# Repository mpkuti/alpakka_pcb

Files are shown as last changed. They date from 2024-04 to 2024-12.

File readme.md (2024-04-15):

# Alpakka PCB

*Alpakka controller Printed Circuit Board reference design*

## Project links
- [Alpakka Manual](https://inputlabs.io/devices/alpakka/manual).
- [Alpakka Firmware](https://github.com/inputlabs/alpakka_firmware).
- [Alpakka PCB](https://github.com/inputlabs/alpakka_pcb). _(you are here)_
- [Alpakka 3D-print](https://github.com/inputlabs/alpakka_case).
- [Input Labs Roadmap](https://github.com/orgs/inputlabs/projects/2/views/2).

## Previews



## Order a PCB from the reference design
For ordering a reference design PCB (with no modifications) is possible to use the pre-built [order files](https://github.com/inputlabs/alpakka_pcb/releases). Check the [manual](https://inputlabs.io/devices/alpakka/manual/diy_pcb) for step-by-step instructions.

## Modify the schematics and PCB

### Dependencies
- [KiCad 8](https://www.kicad.org)

### Change components for SMT pick & place

- Open `.kicad_sch` file in Schematics editor.
- Go to menu `Tools` → `Edit symbol fields`
- Group by field `Group`
- Change id references (`LCSC id` for [JLCPCB](https://jlcpcb.com)).

### Generate order files from sources
- Copy `plugins/kicad_ilo_export.py` into KiCad plugins folder (PCB editor → menu `Tools` → `External plugins` → `Reveal plugins folder`).
- Open `.kicad_pcb` file in PCB editor.
- Use menu `Edit` → `Fill all zones`
- Go to menu `Tools` → `External plugins` → `Refresh plugins`
- Go to menu `Tools` → `External plugins` → `Input Labs: export`
- Files are generated into `order/`

### If the plugin does not load correctly
- Open `Preferences` → `Action plugins`
- Check that the plugin is installed correctly / check errors.

### Procedural zones
Consolidated zones increase `.kicad_pcb` file size significantly, so instead is recommended to load and save the project without consolidation:

- After loading the PCB project: `Edit` → `Fill all zones`.
- Before saving the PCB project: `Edit` → `Unfill all zones`.

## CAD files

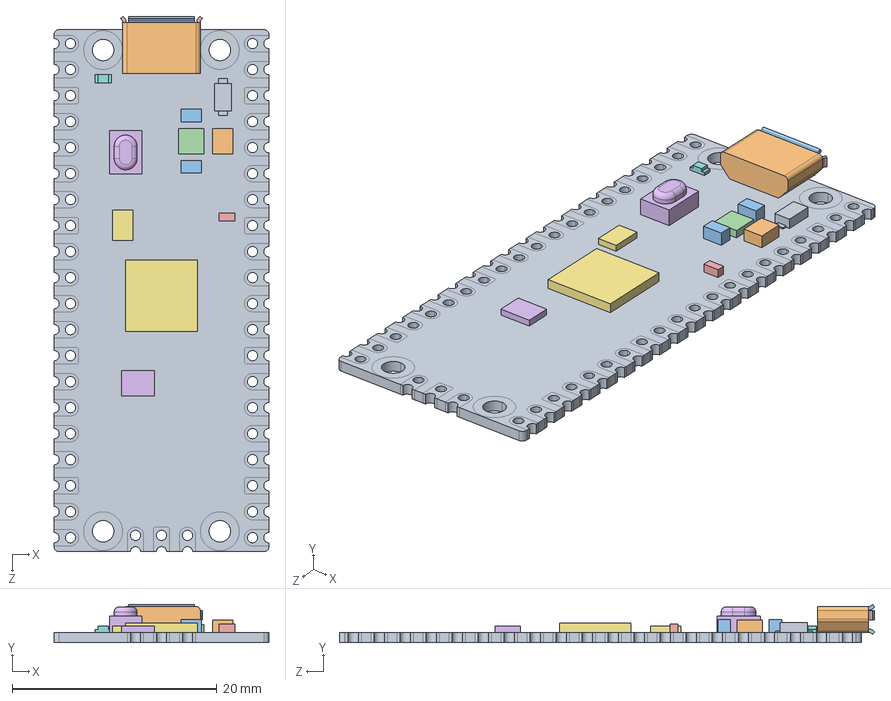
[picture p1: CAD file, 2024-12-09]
symbols/step/Pico-R3.step
21.0 x 3.73 x 52.3 mm
PICO_REF_BOARD.STEP
PICO_REF_USB.STEP
PICO_REF_SWITCH.STEP
PICO_REF_MICROCONTROLLER.STEP
PICO_REF_LED.STEP
PICO_REF_ONSEMI.STEP
PICO_BOURNS.STEP
PICO_MURATA.STEP x 2
PICO_RICHTEK.STEP
PICO_DIODES.STEP
PICO_AEL.STEP
PICO_WINBOND.STEP

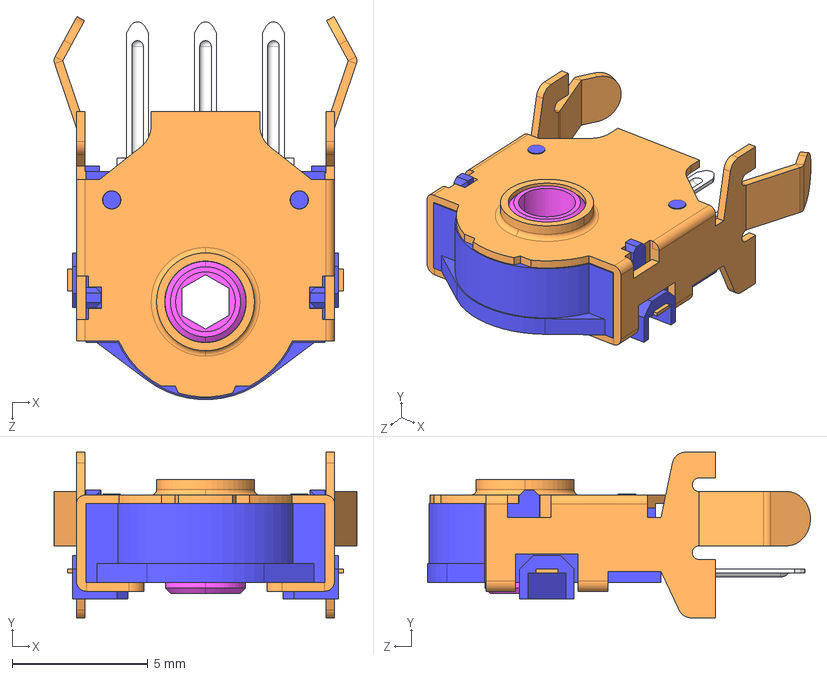
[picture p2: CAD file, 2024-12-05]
symbols/step/EC10E12_H07.STEP
11.1 x 6.10 x 14.1 mm

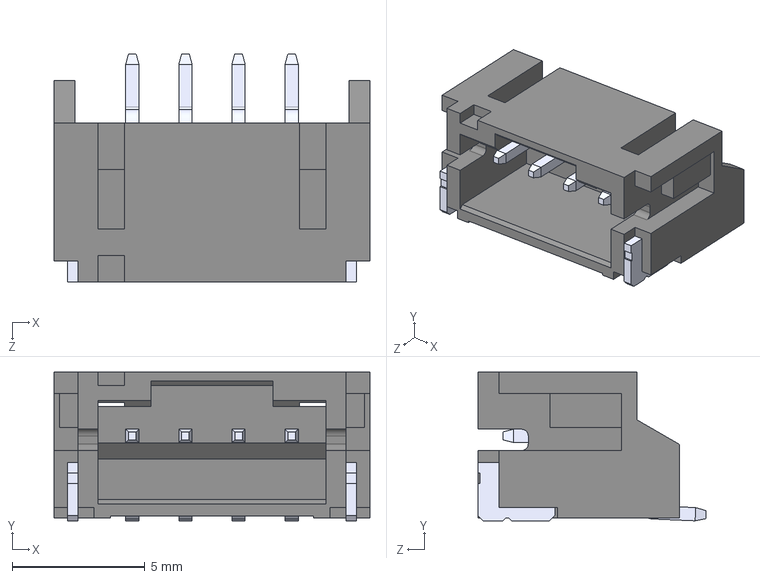
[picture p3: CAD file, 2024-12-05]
symbols/step/S4B-PH-SM4-K-TB (LF)(SN)--3DModel-STEP-56544.STEP
11.9 x 5.60 x 8.60 mm

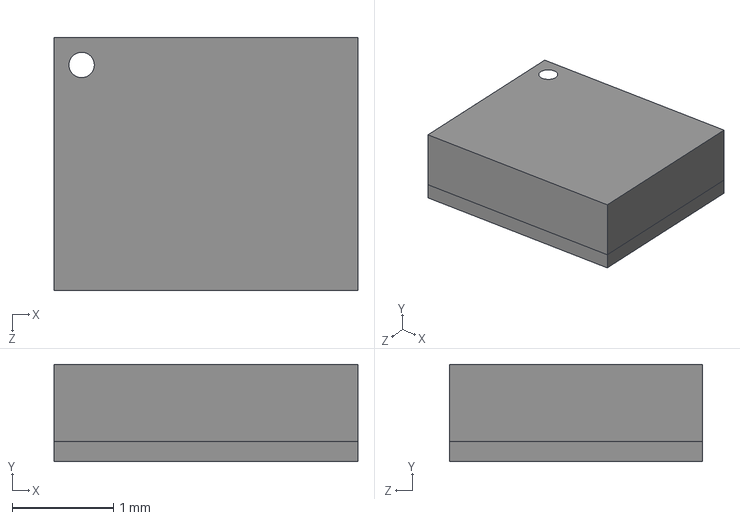
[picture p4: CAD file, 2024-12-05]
symbols/step/LSM6DSRTR.STEP
3.00 x 0.96 x 2.50 mm

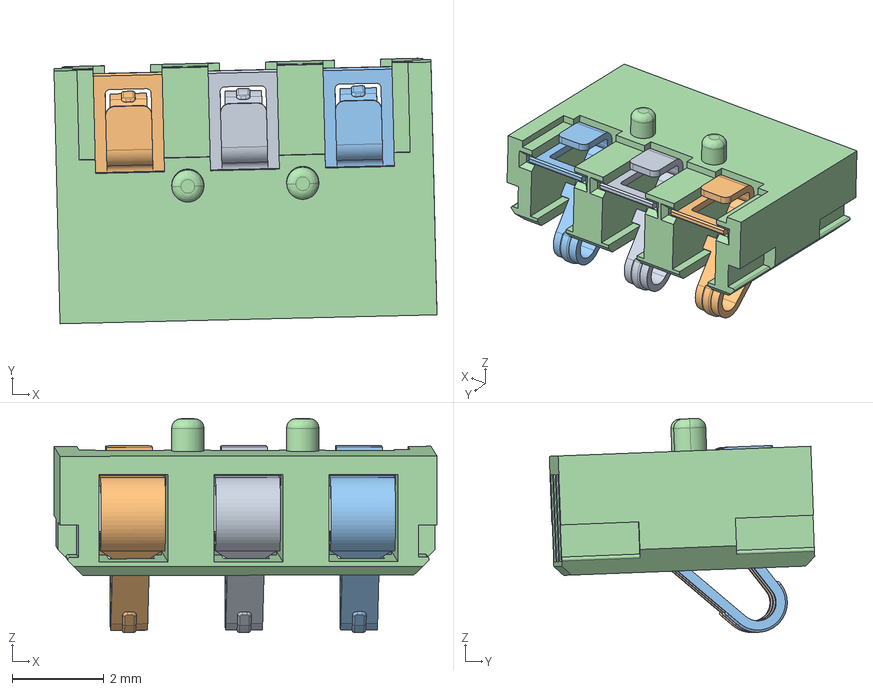
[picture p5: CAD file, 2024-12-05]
symbols/step/304D-262503.stp
8.33 x 5.77 x 4.66 mm
MSBR-4_1
MSBR-3_1
MSBR-2_1
MSBR-1_1

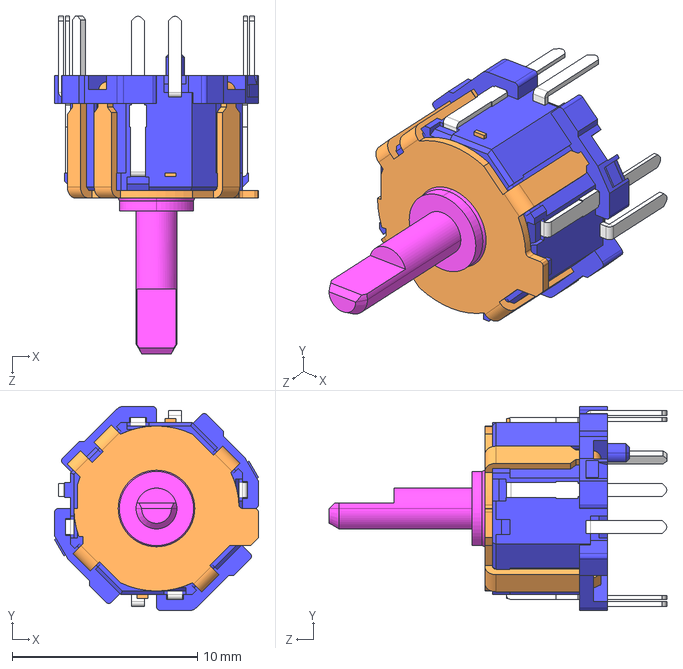
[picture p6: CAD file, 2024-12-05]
symbols/step/RKJXM1015004.STEP
11.0 x 11.0 x 18.2 mm

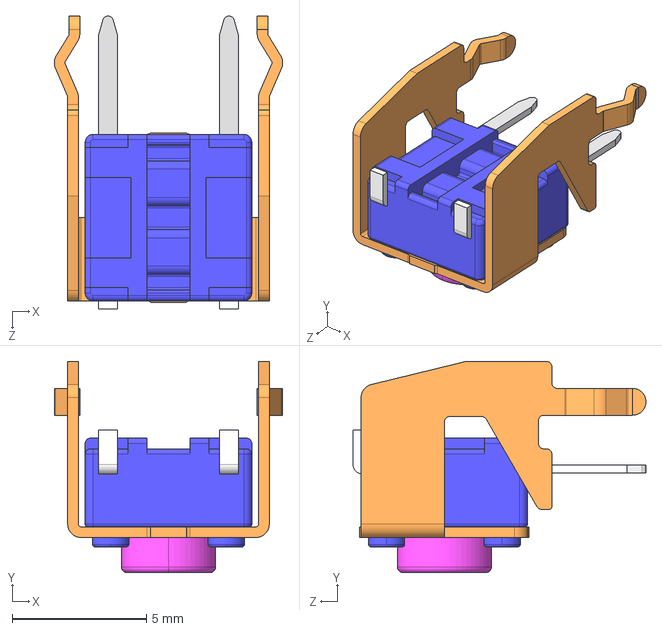
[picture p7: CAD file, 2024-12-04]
symbols/step/SKHHLN.STEP
8.50 x 7.85 x 10.9 mm

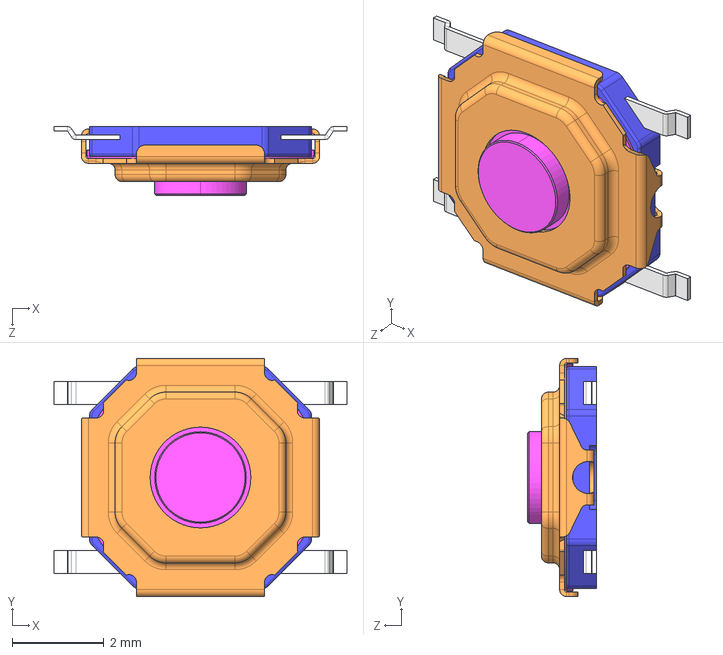
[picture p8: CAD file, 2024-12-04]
symbols/step/SKQGAF.STEP
6.40 x 5.20 x 1.50 mm

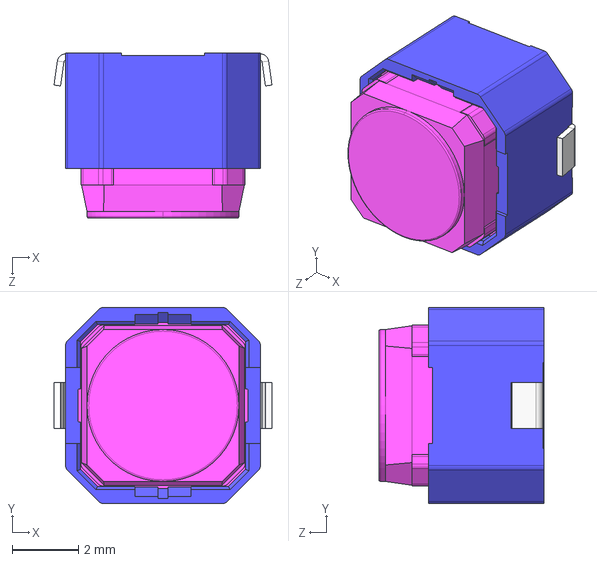
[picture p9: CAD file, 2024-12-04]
symbols/step/SKPMAM.STEP
6.60 x 5.94 x 5.00 mm

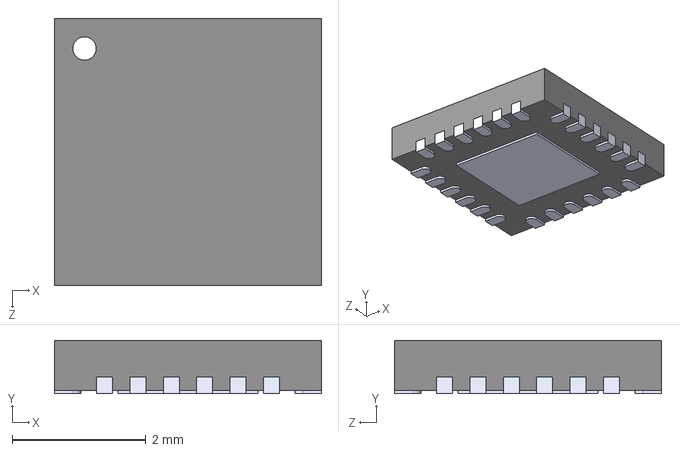
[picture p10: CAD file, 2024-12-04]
symbols/step/PCAL6416AHF,128.STEP
4.00 x 0.8 x 4.00 mm

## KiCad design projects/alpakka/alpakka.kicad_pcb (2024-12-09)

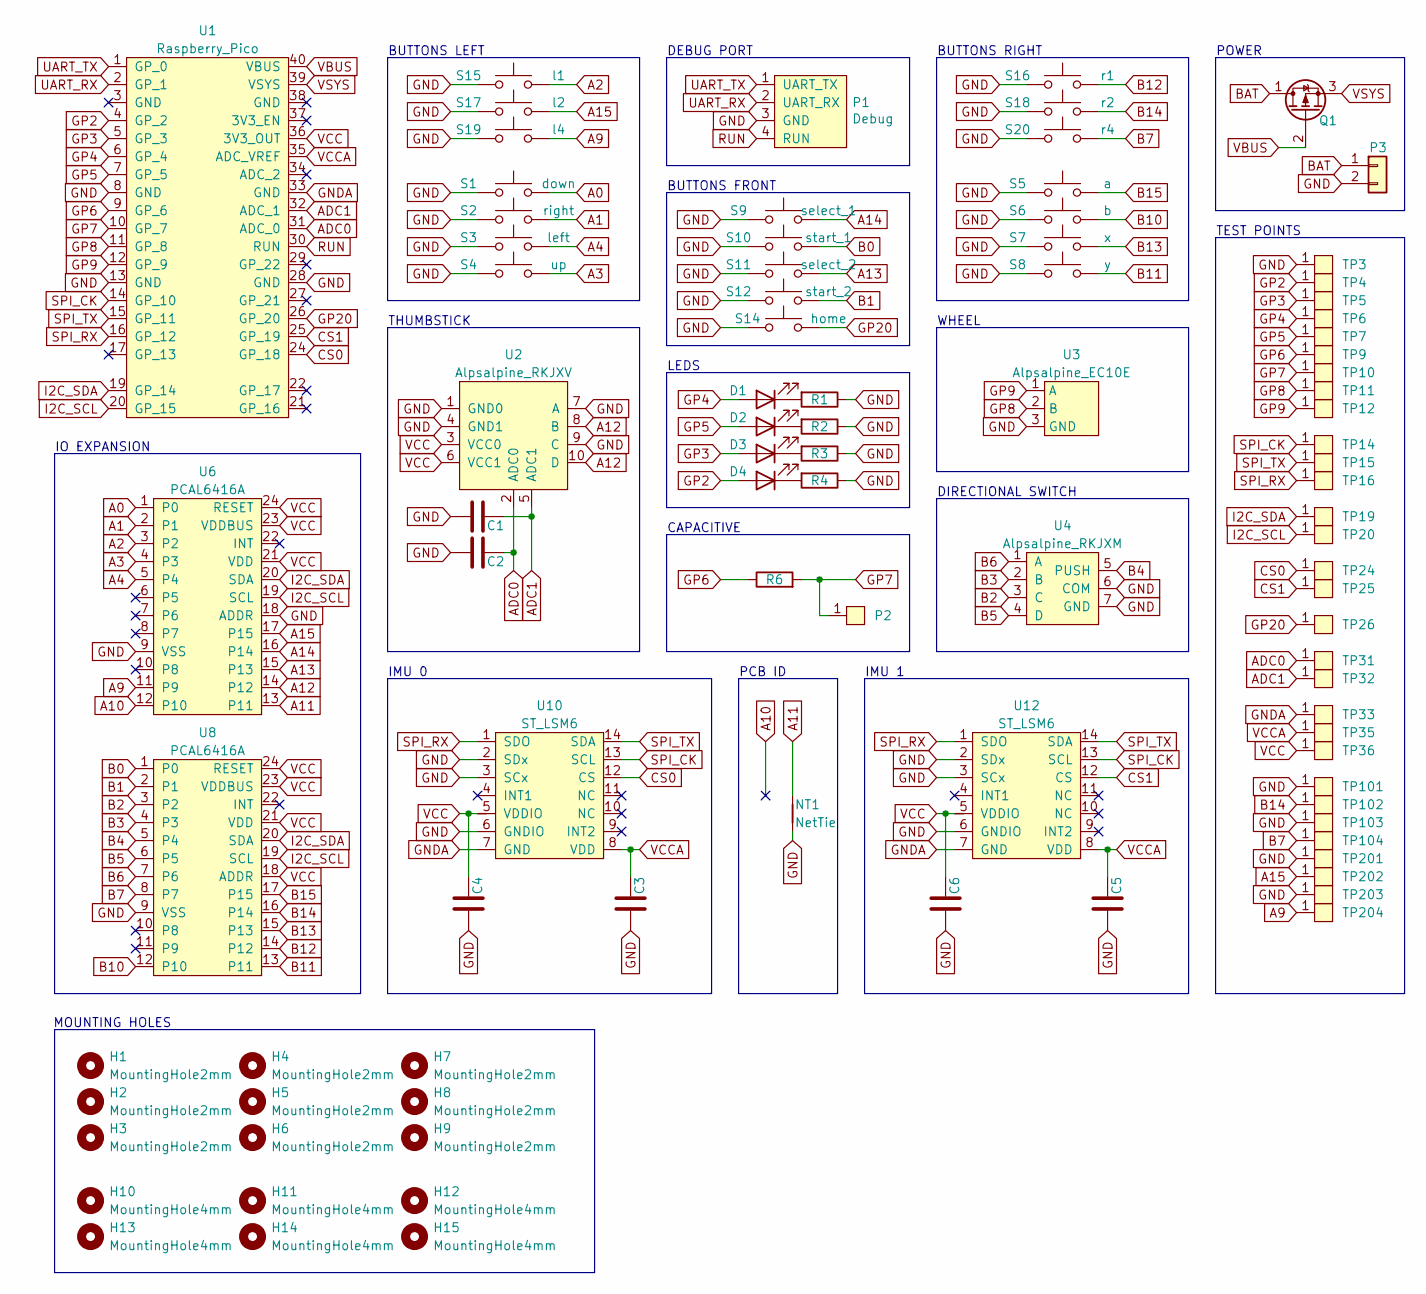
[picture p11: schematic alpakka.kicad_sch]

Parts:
C1, C2, C3, C4, C5, C6: 0.1µF; C_0402_1005Metric_Pad0.74x0.62mm_HandSolder; LCSC C1525
D1, D2, D3, D4: Diode; D_0603_1608Metric_Pad1.05x0.95mm_HandSolder; LCSC C2290
H1, H2, H3, H4, H5, H6, H7, H8, H9: MountingHole2mm; NPTH_2mm
H10, H11, H12, H13, H14, H15: MountingHole4mm; NPTH_4mm
NT1: NetTie; NetTie-2_SMD_Pad0.5mm
P1: Debug; JST_S4B-PH-SM4-K-TB; mouser# 306-S4BPHSM4KTBLFSN; LCSC C265332
P2: Endpoint; 304D-262503; LCSC C707322
P3: Conn_01x02; JST_PH_2_TH
Q1: Q_PMOS_DGS; SOT-23-DGS; digikey# DMG2305UX-7DICT-ND
R1, R2, R3, R4: 20Ω; R_0603_1608Metric_Pad0.98x0.95mm_HandSolder; LCSC C22950
R6: 510kΩ; R_0402_1005Metric_Pad0.72x0.64mm_HandSolder; LCSC C11616
S1: down; Alpsalpine_SKPM; LCSC C115348
S2: right; Alpsalpine_SKPM; LCSC C115348
S3: left; Alpsalpine_SKPM; LCSC C115348
S4: up; Alpsalpine_SKPM; LCSC C115348
S5: a; Alpsalpine_SKPM; LCSC C115348
S6: b; Alpsalpine_SKPM; LCSC C115348
S7: x; Alpsalpine_SKPM; LCSC C115348
S8: y; Alpsalpine_SKPM; LCSC C115348
S9: select_1; Alpsalpine_SKPM; LCSC C115348
S10: start_1; Alpsalpine_SKPM; LCSC C115348
S11: select_2; Alpsalpine_SKPM; LCSC C115348
S12: start_2; Alpsalpine_SKPM; LCSC C115348
S14: home; Alpsalpine_SKPM; LCSC C115348
S15: l1; Alpsalpine_SKHHL; LCSC C125031
S16: r1; Alpsalpine_SKHHL; LCSC C125031
S17: l2; Alpsalpine_SKQG; LCSC C202424
S18: r2; Alpsalpine_SKQG; LCSC C202424
S19: l4; Alpsalpine_SKQG; LCSC C202424
S20: r4; Alpsalpine_SKQG; LCSC C202424
TP3, TP4, TP5, TP6, TP7, TP9, TP10, TP11, TP12, TP14, TP15, TP16, TP19, TP20, TP24, TP25, TP26, TP31, TP32, TP33, TP35, TP36, TP101, TP102, TP103, TP104, TP201, TP202, TP203, TP204: Endpoint; Pad_1mm
U1: Raspberry_Pico; LCSC C7203002
U2: Alpsalpine_RKJXV; Alpsalpine_RKJXV122400R; mouser# 688-RKJXV122400R; LCSC C918854
U3: Alpsalpine_EC10E; LCSC C110291
U4: Alpsalpine_RKJXM; Alpsalpine_RKJXM1015004; LCSC C97432
U6, U8: PCAL6416A; QFN24; LCSC C2652287
U10, U12: ST_LSM6; LGA14; LCSC C784817

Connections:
A0: S1.2, U6.1 (P0)
A1: S2.2, U6.2 (P1)
A2: S15.2, U6.3 (P2)
A3: S4.2, U6.4 (P3)
A4: S3.2, U6.5 (P4)
A9: S19.2, TP204.1, U6.11 (P9)
A10: U6.12 (P10)
A11: NT1.2, U6.13 (P11)
A12: U2.8 (B), U2.10 (D), U6.14 (P12)
A13: S11.2, U6.15 (P13)
A14: S9.2, U6.16 (P14)
A15: S17.2, TP202.1, U6.17 (P15)
ADC0: C2.2, TP31.1, U1.31 (ADC_0), U2.2 (ADC0)
ADC1: C1.2, TP32.1, U1.32 (ADC_1), U2.5 (ADC1)
B0: S10.2, U8.1 (P0)
B1: S12.2, U8.2 (P1)
B2: U4.3 (C), U8.3 (P2)
B3: U4.2 (B), U8.4 (P3)
B4: U4.5 (PUSH), U8.5 (P4)
B5: U4.4 (D), U8.6 (P5)
B6: U4.1 (A), U8.7 (P6)
B7: S20.2, TP104.1, U8.8 (P7)
B10: S6.2, U8.12 (P10)
B11: S8.2, U8.13 (P11)
B12: S16.2, U8.14 (P12)
B13: S7.2, U8.15 (P13)
B14: S18.2, TP102.1, U8.16 (P14)
B15: S5.2, U8.17 (P15)
BAT: P3.1, Q1.1 (D)
CS0: TP24.1, U1.24 (GP_18), U10.12 (CS)
CS1: TP25.1, U1.25 (GP_19), U12.12 (CS)
GND: C1.1, C2.1, C3.1, C4.1, C5.1, C6.1, NT1.1, P1.3 (GND), P3.2, R1.1, R2.1, R3.1, R4.1, S1.1, S2.1, S3.1, S4.1, S5.1, S6.1, S7.1, S8.1, S9.1, S10.1, S11.1, S12.1, S14.1, S15.1, S16.1, S17.1, S18.1, S19.1, S20.1, TP3.1, TP101.1, TP103.1, TP201.1, TP203.1, U1.8 (GND), U1.13 (GND), U1.28 (GND), U2.1 (GND0), U2.4 (GND1), U2.7 (A), U2.9 (C), U3.3 (GND), U4.6 (COM), U4.7 (GND), U6.9 (VSS), U6.18 (ADDR), U8.9 (VSS), U10.2 (SDx), U10.3 (SCx), U10.6 (GNDIO), U12.2 (SDx), U12.3 (SCx), U12.6 (GNDIO)
GNDA: TP33.1, U1.33 (GND), U10.7 (GND), U12.7 (GND)
GP2: D4.2 (A), TP4.1, U1.4 (GP_2)
GP3: D3.2 (A), TP5.1, U1.5 (GP_3)
GP4: D1.2 (A), TP6.1, U1.6 (GP_4)
GP5: D2.2 (A), TP7.1, U1.7 (GP_5)
GP6: R6.1, TP9.1, U1.9 (GP_6)
GP7: P2.1, R6.2, TP10.1, U1.10 (GP_7)
GP8: TP11.1, U1.11 (GP_8), U3.2 (B)
GP9: TP12.1, U1.12 (GP_9), U3.1 (A)
GP20: S14.2, TP26.1, U1.26 (GP_20)
I2C_SCL: TP20.1, U1.20 (GP_15), U6.19 (SCL), U8.19 (SCL)
I2C_SDA: TP19.1, U1.19 (GP_14), U6.20 (SDA), U8.20 (SDA)
unnamed: D1.1 (K), R1.2
unnamed: D2.1 (K), R2.2
unnamed: D3.1 (K), R3.2
unnamed: D4.1 (K), R4.2
RUN: P1.4 (RUN), U1.30 (RUN)
SPI_CK: TP14.1, U1.14 (GP_10), U10.13 (SCL), U12.13 (SCL)
SPI_RX: TP16.1, U1.16 (GP_12), U10.1 (SDO), U12.1 (SDO)
SPI_TX: TP15.1, U1.15 (GP_11), U10.14 (SDA), U12.14 (SDA)
UART_RX: P1.2 (UART_RX), U1.2 (GP_1)
UART_TX: P1.1 (UART_TX), U1.1 (GP_0)
VBUS: Q1.2 (G), U1.40 (VBUS)
VCC: C4.2, C6.2, TP36.1, U1.36 (3V3_OUT), U2.3 (VCC0), U2.6 (VCC1), U6.21 (VDD), U6.23 (VDDBUS), U6.24 (RESET), U8.18 (ADDR), U8.21 (VDD), U8.23 (VDDBUS), U8.24 (RESET), U10.5 (VDDIO), U12.5 (VDDIO)
VCCA: C3.2, C5.2, TP35.1, U1.35 (ADC_VREF), U10.8 (VDD), U12.8 (VDD)
VSYS: Q1.3 (S), U1.39 (VSYS)

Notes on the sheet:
WHEEL
DEBUG PORT
THUMBSTICK
IMU 0
PCB ID
IMU 1
BUTTONS FRONT
TEST POINTS
MOUNTING HOLES
DIRECTIONAL SWITCH
CAPACITIVE
IO EXPANSION
LEDS
BUTTONS LEFT
BUTTONS RIGHT
POWER

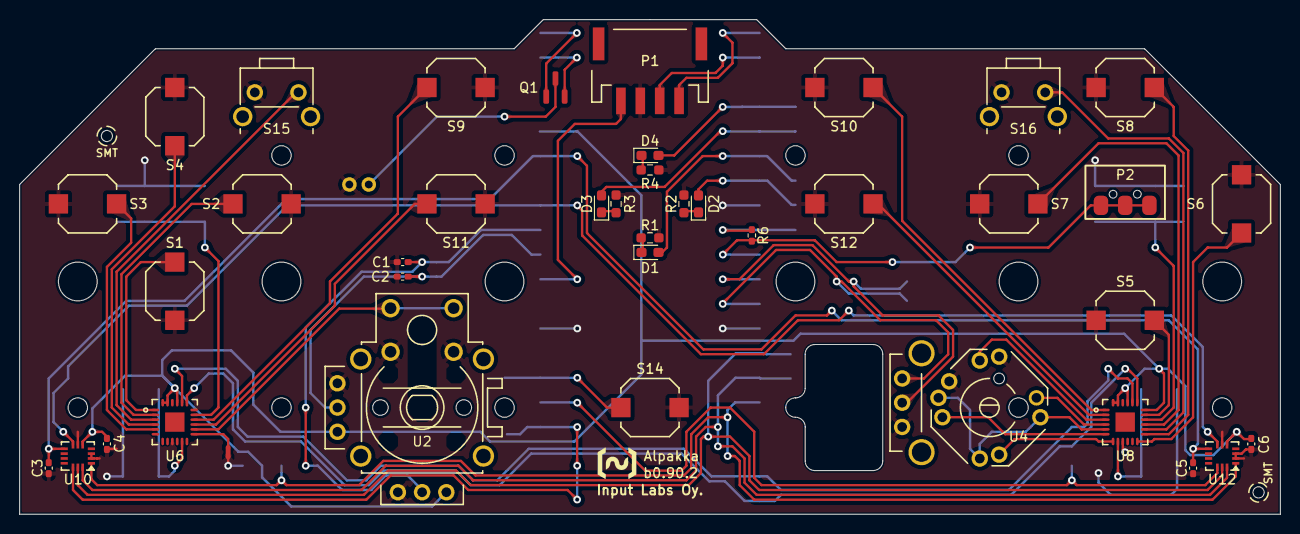
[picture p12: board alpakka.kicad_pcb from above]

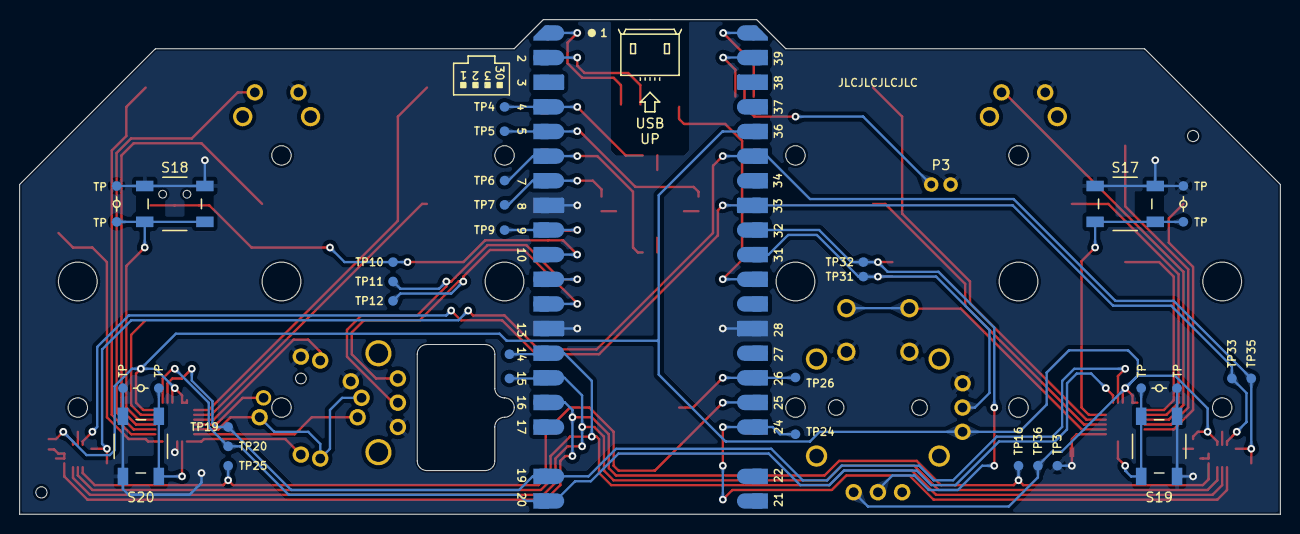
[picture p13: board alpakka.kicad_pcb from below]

Board: 2 copper layers, 130.0 x 51.0 mm, 92 parts (36 on the bottom side), 57 nets.

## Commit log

2024-04-15 Project updated to kicad 8.0, Moved project into projects folder
    [alpakka.kicad_pcb, alpakka.kicad_sch]
2024-12-04 fill some order info to BOM, also add 3d models of some parts
    [PCAL6416AHF,128.STEP, SKHHLN.STEP, SKPMAM.STEP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]
2024-12-05 add joystick 3d model and order info
    [alpakka.kicad_pcb, alpakka.kicad_sch]
2024-12-05 add info + 3d model for the right joystick
    [RKJXM1015004.STEP, alpakka.kicad_pcb, alpakka.kicad_sch]
2024-12-05 replace capacitive contact part with one with 3d model
    [304D-262503.stp, alpakka.kicad_pcb, alpakka.kicad_sch]
2024-12-05 add resistor order info
    [alpakka.kicad_pcb, alpakka.kicad_sch]
2024-12-05 mod button keepout zone
    [alpakka.kicad_pcb, alpakka.kicad_sch]
2024-12-05 add 3d model of the debug connector
    [EC10E12_H07.STEP, LSM6DSRTR.STEP, S4B-PH-SM4-K-TB (LF)(SN)--3DModel-STEP-56544.STEP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]
2024-12-09 add Rpi Pico 3d model, also other mods
    [Pico-R3.step, alpakka.kicad_pcb, alpakka.kicad_sch]
